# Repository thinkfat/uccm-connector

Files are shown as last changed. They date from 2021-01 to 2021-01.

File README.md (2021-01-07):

uccm-connector
==============

Connector board for UCCM GPSDO modules

This repository contains a KiCAD 5 project with a connector board for UCCM GPSDO boards.

Schematic
---------

The *doc* folder contains the schematic as PDF

Fabrication
-----------

The *gerber* folder contains Gerber plots and drill files. You can just ZIP this folder and upload it e.g. to JLCPCB to have the boards made.

BOM
---

Many of the passive parts are just generic beach sand stuff. If you look into the *bom* folder, there's a 
file _ibom.html_ that, if you open it in a browser, will give you an interactive part list that can guide you
with part ordering and assembly.

However, there's a few components that must match the footprint or are otherwise hard to find:

- DC jack: Lumberg NEB21R
- FPC socket: Molex 54132-5033
- FPC jumper cable: Molex 15166-0537
- Switching regulator: TI LMR14030SDDAR
- Storage coil: Coilcraft XAL5030-222MEC
- Flyback diode: Diodes B330BE-13
- Electrolytic caps: Panasonic EEE-FT1V470AR should fit
- Switcher input caps: TDK C3216X5R1H685K160AB
- Trimpot: Bourns 3313J-1-503E
- RS232 line converter: TI MAX3232ECDR
- DC input choke: Murata LQM31PN1R0M00L
- Reverse polarity protection: Diodes ES2BA-13-F
- LDO: APE8865N-33-HF-3

  this part is not really critical, just make sure you order a matching pin-out and take care of the dimensioning of the input and output caps.
  In fact even for this particular part you can deviate from the BOM and use 1µF MLCCs in 0805 size, they tend to be cheaper than the 4.7µF that
  are in the schematic.

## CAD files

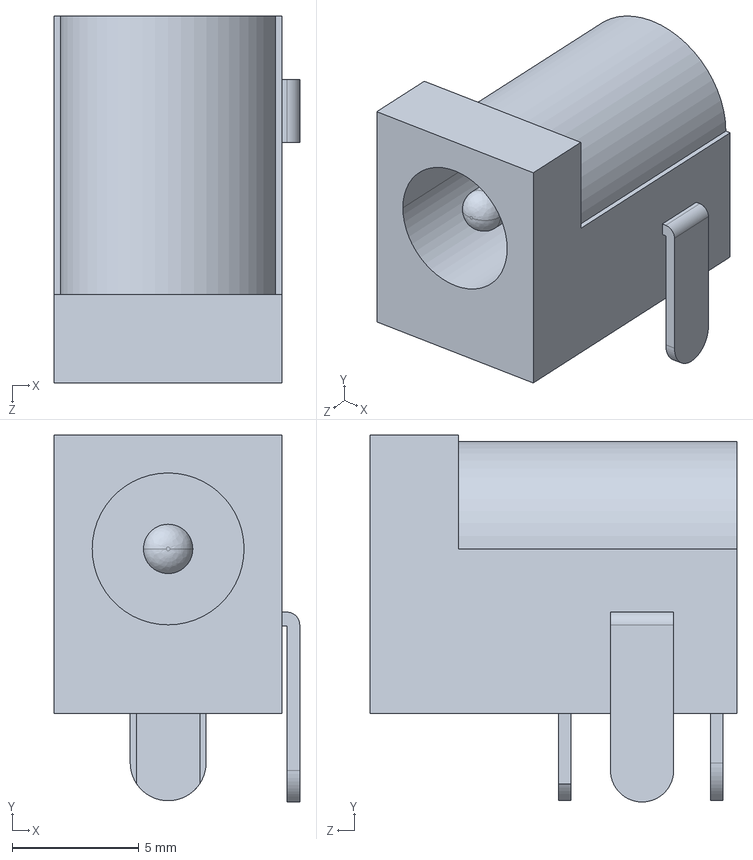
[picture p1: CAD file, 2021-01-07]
User Library-NEB21R.step
9.70 x 14.5 x 14.5 mm

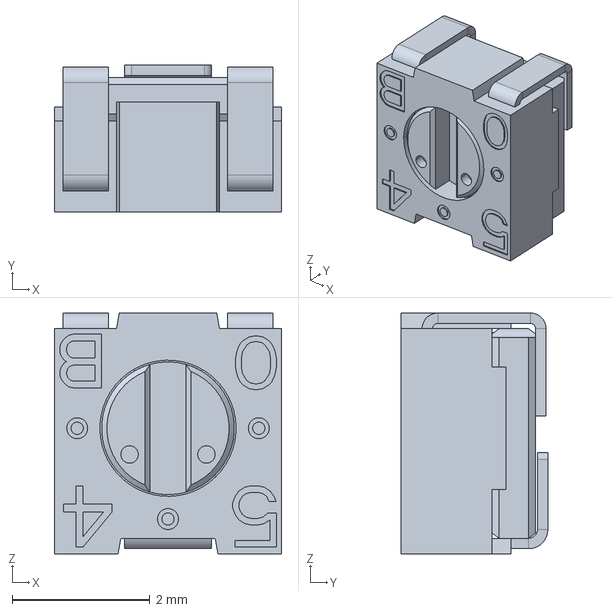
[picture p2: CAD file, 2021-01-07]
3313j-1-101e.stp
3.30 x 2.13 x 3.51 mm

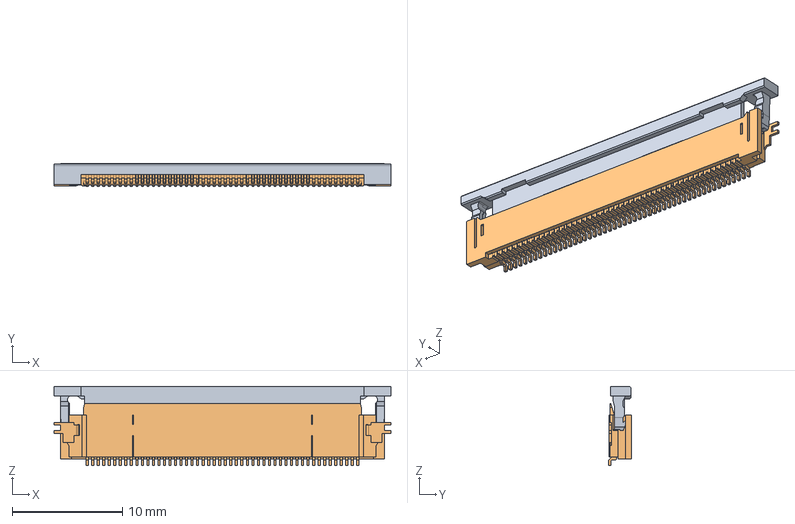
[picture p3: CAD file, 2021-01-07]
54132-5097.stp
30.5 x 2.05 x 7.15 mm

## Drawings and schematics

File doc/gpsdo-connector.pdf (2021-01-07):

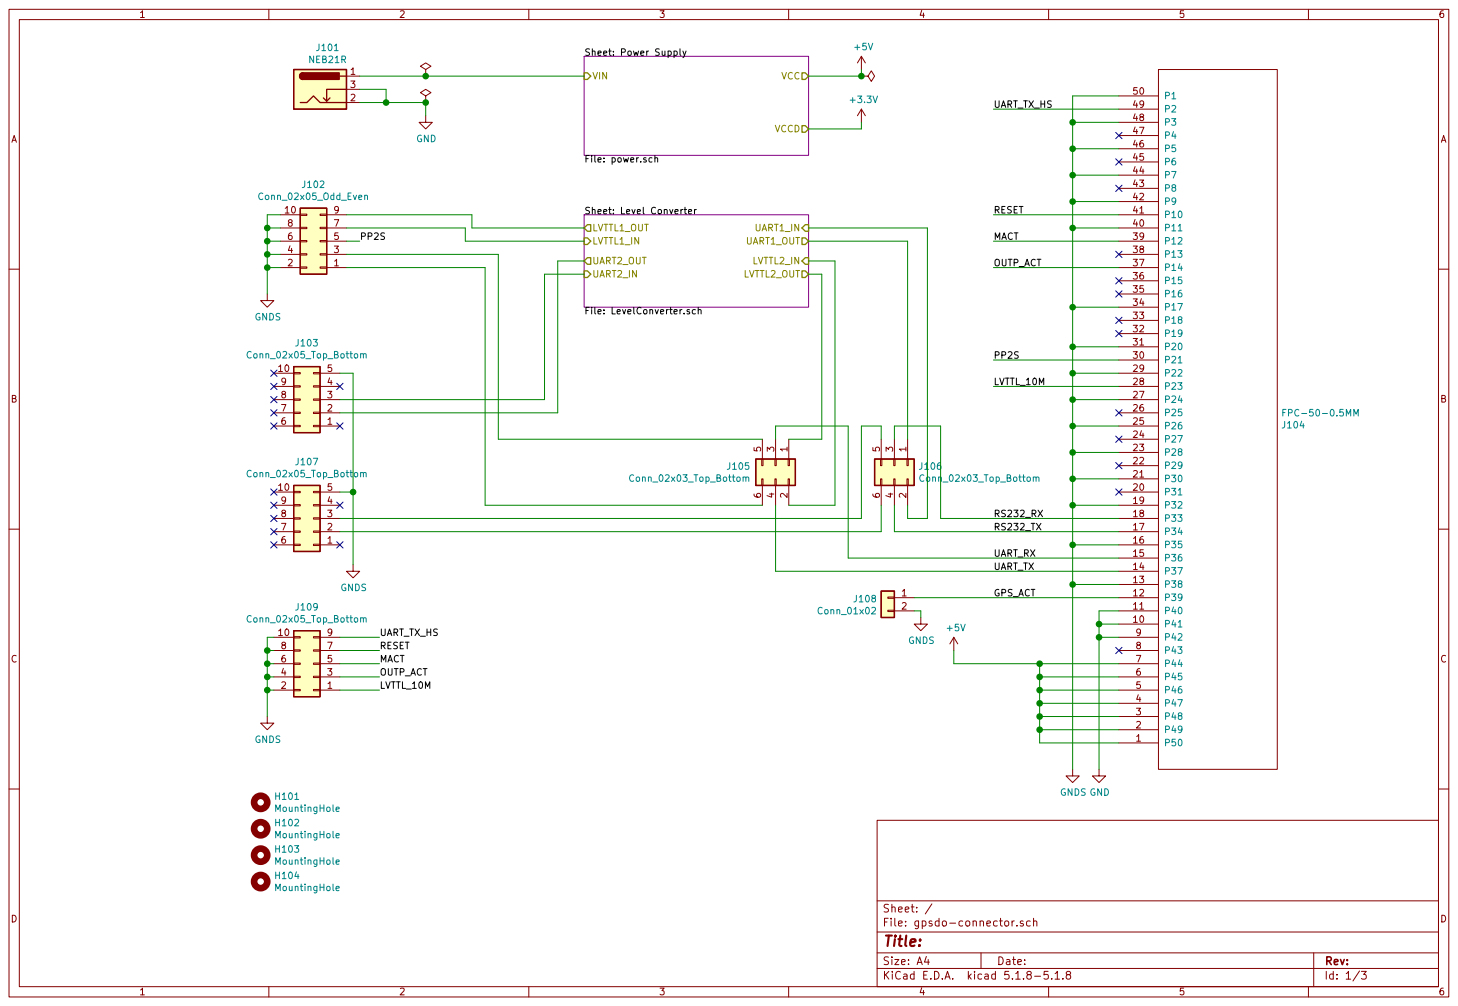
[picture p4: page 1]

Sheet: Level Converter File: LevelConverter.sch
LVTTL1_IN

File: gpsdo-connector.sch Sheet: /

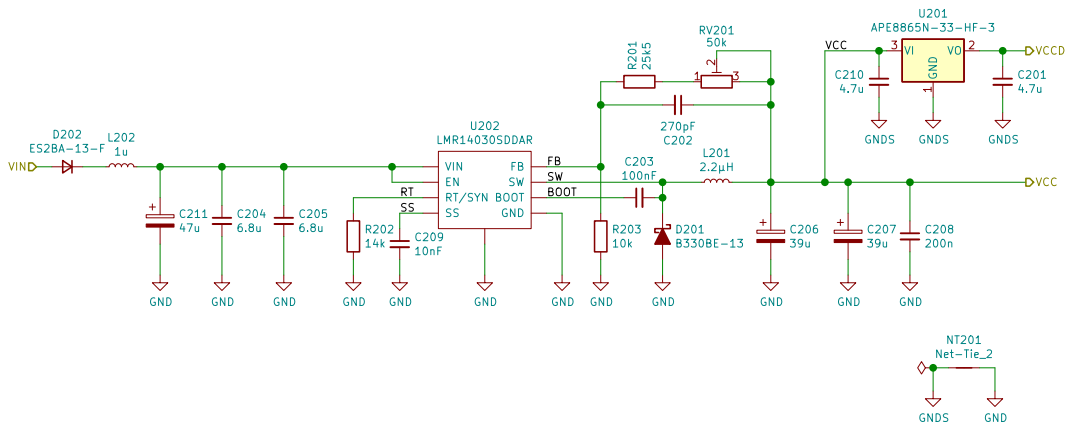
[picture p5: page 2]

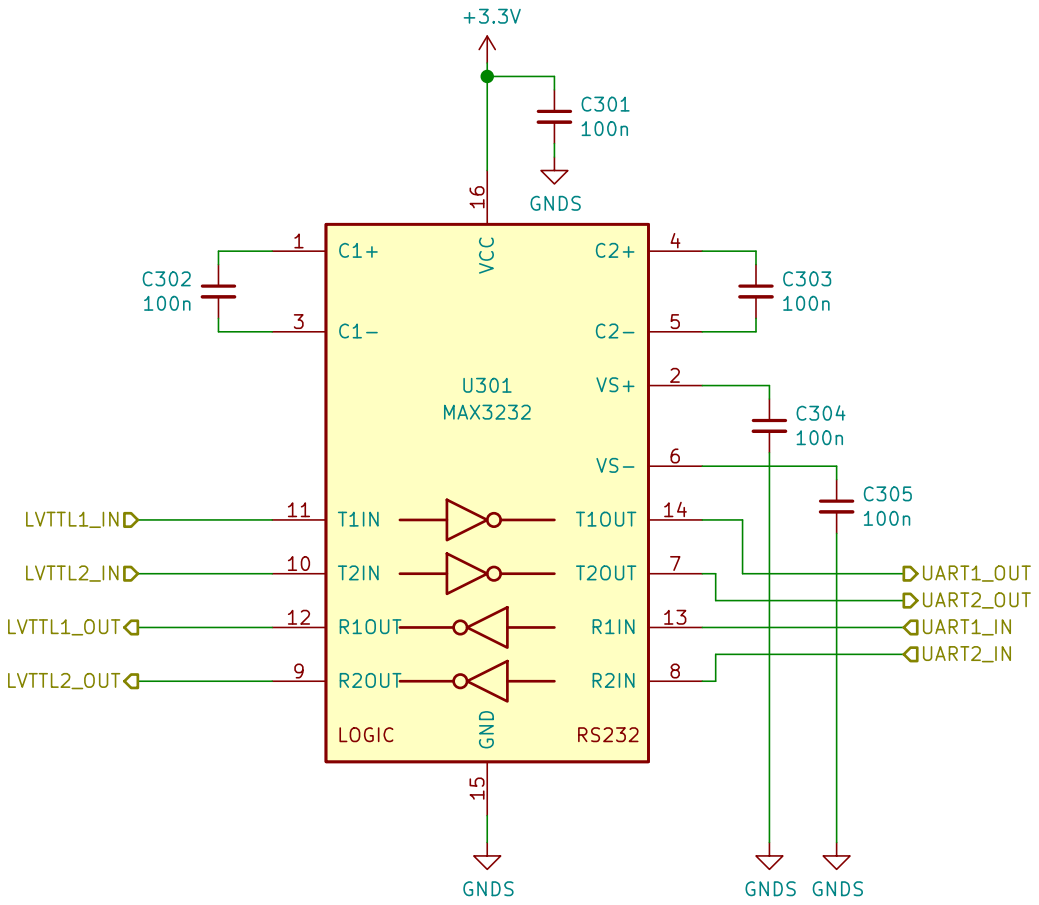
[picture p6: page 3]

Id: 3/3 Title: File: LevelConverter.sch Sheet: /Level Converter/

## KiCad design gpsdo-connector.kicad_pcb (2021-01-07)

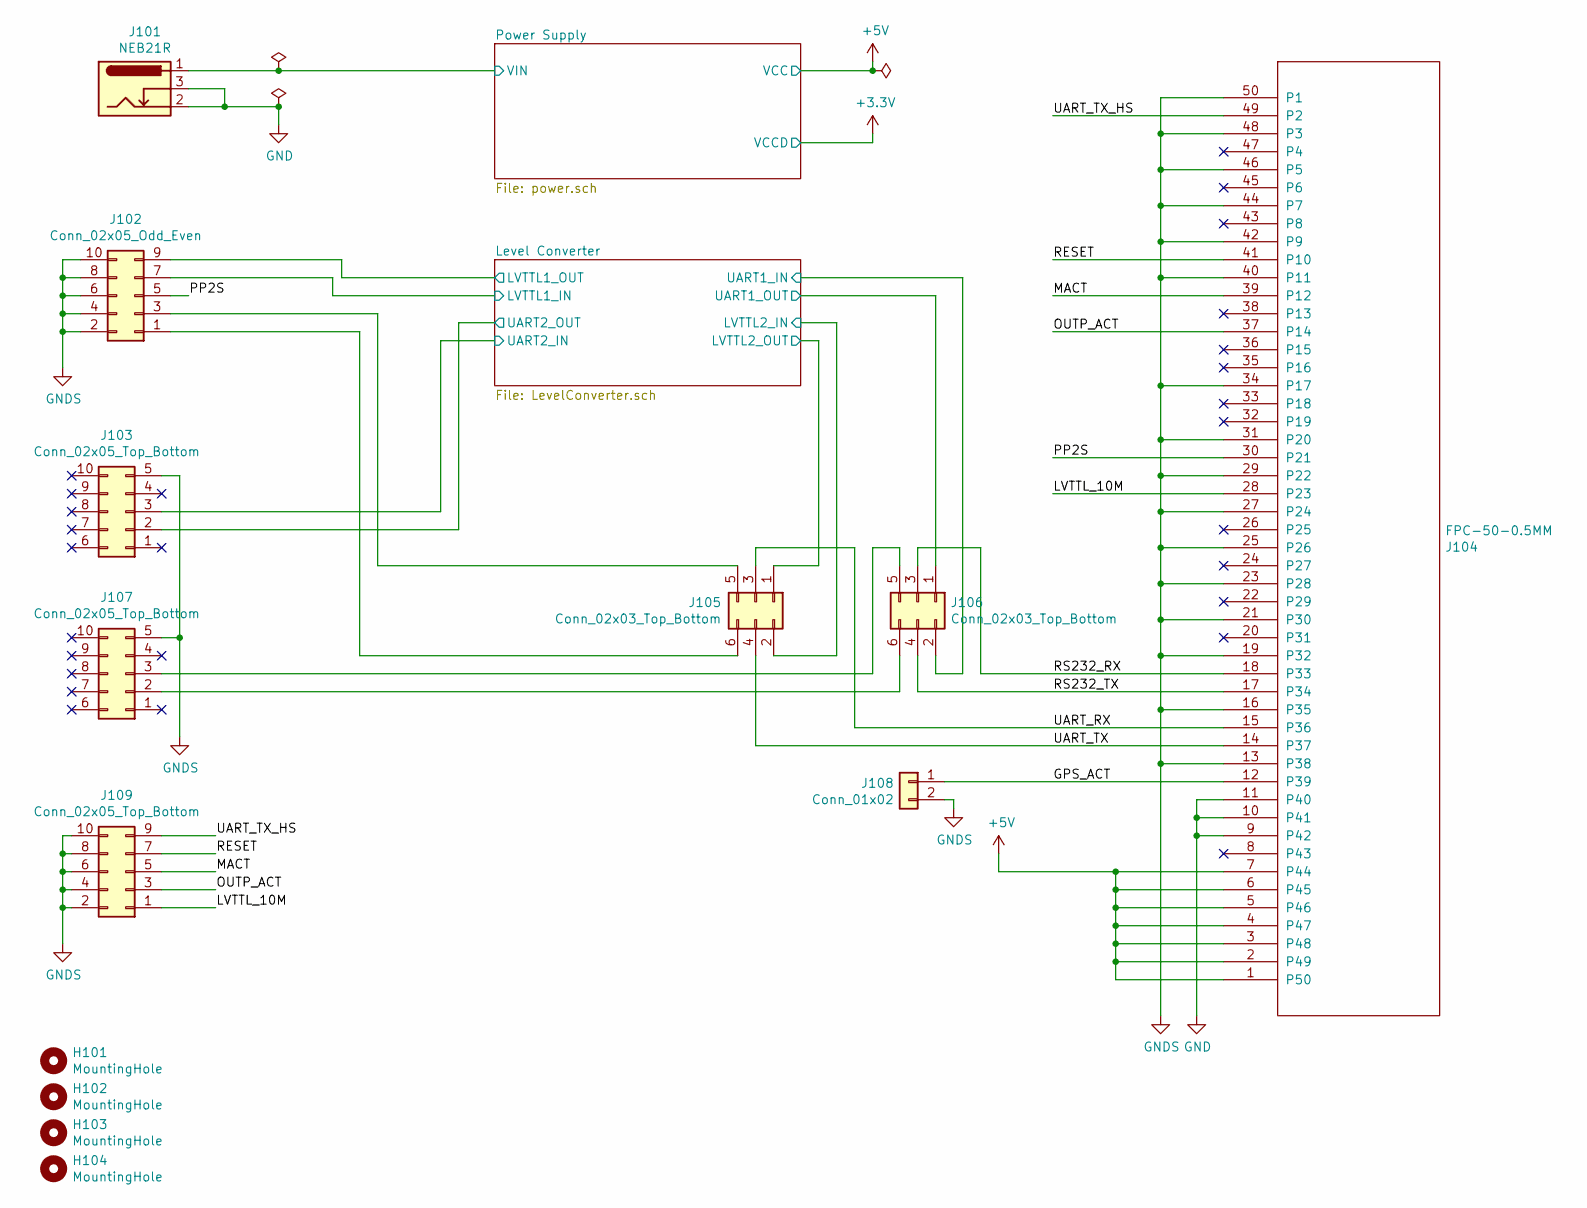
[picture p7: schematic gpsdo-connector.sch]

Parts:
H101, H102, H103, H104: MountingHole; MountingHole_3.2mm_M3_DIN965
J101: NEB21R
J102: Conn_02x05_Odd_Even; IDC-Header_2x05_P2.54mm_Vertical
J103, J107: Conn_02x05_Top_Bottom; IDC-Header_2x05_P2.54mm_Vertical
J104: FPC-50-0.5MM; Molex_54132-5033_1x50-1MP_P0.5mm_Horizontal
J105, J106: Conn_02x03_Top_Bottom; PinHeader_2x03_P2.54mm_Vertical
J108: Conn_01x02; PinHeader_1x02_P2.54mm_Vertical
J109: Conn_02x05_Top_Bottom; PinHeader_2x05_P2.54mm_Vertical

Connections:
+5V: J104.1 (P50), J104.2 (P49), J104.3 (P48), J104.4 (P47), J104.5 (P46), J104.6 (P45), J104.7 (P44); also elsewhere on the board
/GPS_ACT: J104.12 (P39), J108.1
/LVTTL_10M: J104.28 (P23), J109.1
/Level Converter/LVTTL1_IN: J102.7; also elsewhere on the board
/Level Converter/LVTTL1_OUT: J102.9; also elsewhere on the board
/Level Converter/LVTTL2_IN: J105.2; also elsewhere on the board
/Level Converter/LVTTL2_OUT: J105.1; also elsewhere on the board
/Level Converter/UART1_IN: J106.2; also elsewhere on the board
/Level Converter/UART1_OUT: J106.1; also elsewhere on the board
/Level Converter/UART2_IN: J103.3; also elsewhere on the board
/Level Converter/UART2_OUT: J103.2; also elsewhere on the board
/MACT: J104.39 (P12), J109.5
/OUTP_ACT: J104.37 (P14), J109.3
/PP2S: J102.5, J104.30 (P21)
/Power Supply/VIN: J101.1; also elsewhere on the board
/RESET: J104.41 (P10), J109.7
/RS232_RX: J104.18 (P33), J106.3
/RS232_TX: J104.17 (P34), J106.4
/UART_RX: J104.15 (P36), J105.3
/UART_TX: J104.14 (P37), J105.4
/UART_TX_HS: J104.49 (P2), J109.9
GND: J101.2, J101.3, J104.9 (P42), J104.10 (P41), J104.11 (P40); also elsewhere on the board
GNDS: J102.2, J102.4, J102.6, J102.8, J102.10, J103.5, J104.13 (P38), J104.16 (P35), J104.19 (P32), J104.21 (P30), J104.23 (P28), J104.25 (P26), J104.27 (P24), J104.29 (P22), J104.31 (P20), J104.34 (P17), J104.40 (P11), J104.42 (P9), J104.44 (P7), J104.46 (P5), J104.48 (P3), J104.50 (P1), J107.5, J108.2, J109.2, J109.4, J109.6, J109.8, J109.10; also elsewhere on the board
unnamed: J102.1, J105.6
unnamed: J102.3, J105.5
unnamed: J106.5, J107.3
unnamed: J106.6, J107.2

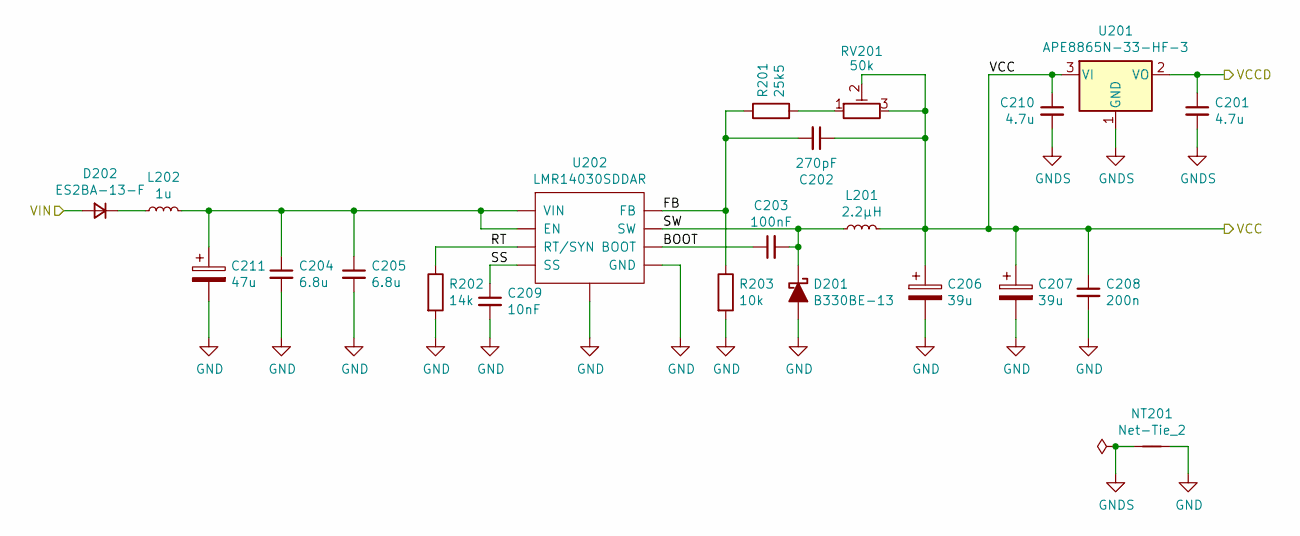
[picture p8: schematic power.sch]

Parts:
C201, C210: 4.7u; C_0805_2012Metric
C202: 270pF; C_0805_2012Metric
C203: 100nF; C_0805_2012Metric
C204, C205: 6.8u; C_1206_3216Metric
C206, C207: 39u; CP_Elec_5x5.9
C208: 200n; C_0805_2012Metric
C209: 10nF; C_0805_2012Metric
C211: 47u; CP_Elec_5x5.9
D201: B330BE-13; D_SMB
D202: ES2BA-13-F; D_SMA
L201: 2.2µH; L_Coilcraft_XAL5030
L202: 1u; L_1206_3216Metric
NT201: Net-Tie_2; NetTie-2_SMD_Pad2.0mm
R201: 25k5; R_0805_2012Metric
R202: 14k; R_0805_2012Metric_Pad1.15x1.40mm_HandSolder
R203: 10k; R_0805_2012Metric_Pad1.15x1.40mm_HandSolder
RV201: 50k; Trimpot_Bourns_3313J-1
U201: APE8865N-33-HF-3; SOT-23
U202: LMR14030SDDAR; TI_SO-PowerPAD-8

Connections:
+3V3: C201.1, U201.2 (VO); also elsewhere on the board
+5V: C202.1, C206.1, C207.1, C208.1, C210.1, L201.2, RV201.2, RV201.3, U201.3 (VI); also elsewhere on the board
/Power Supply/BOOT: C203.1, U202.1 (BOOT)
/Power Supply/FB: C202.2, R201.1, R203.1, U202.5 (FB)
/Power Supply/RT: R202.1, U202.4 (RT/SYN)
/Power Supply/SS: C209.1, U202.6 (SS)
/Power Supply/SW: C203.2, D201.1 (K), L201.1, U202.8 (SW)
/Power Supply/VIN: D202.2 (A); also elsewhere on the board
GND: C204.2, C205.2, C206.2, C207.2, C208.2, C209.2, C211.2, D201.2 (A), NT201.2, R202.2, R203.2, U202.7 (GND), U202.9; also elsewhere on the board
GNDS: C201.2, C210.2, NT201.1, U201.1 (GND); also elsewhere on the board
unnamed: C204.1, C205.1, C211.1, L202.2, U202.2 (VIN), U202.3 (EN)
unnamed: D202.1 (K), L202.1
unnamed: R201.2, RV201.1

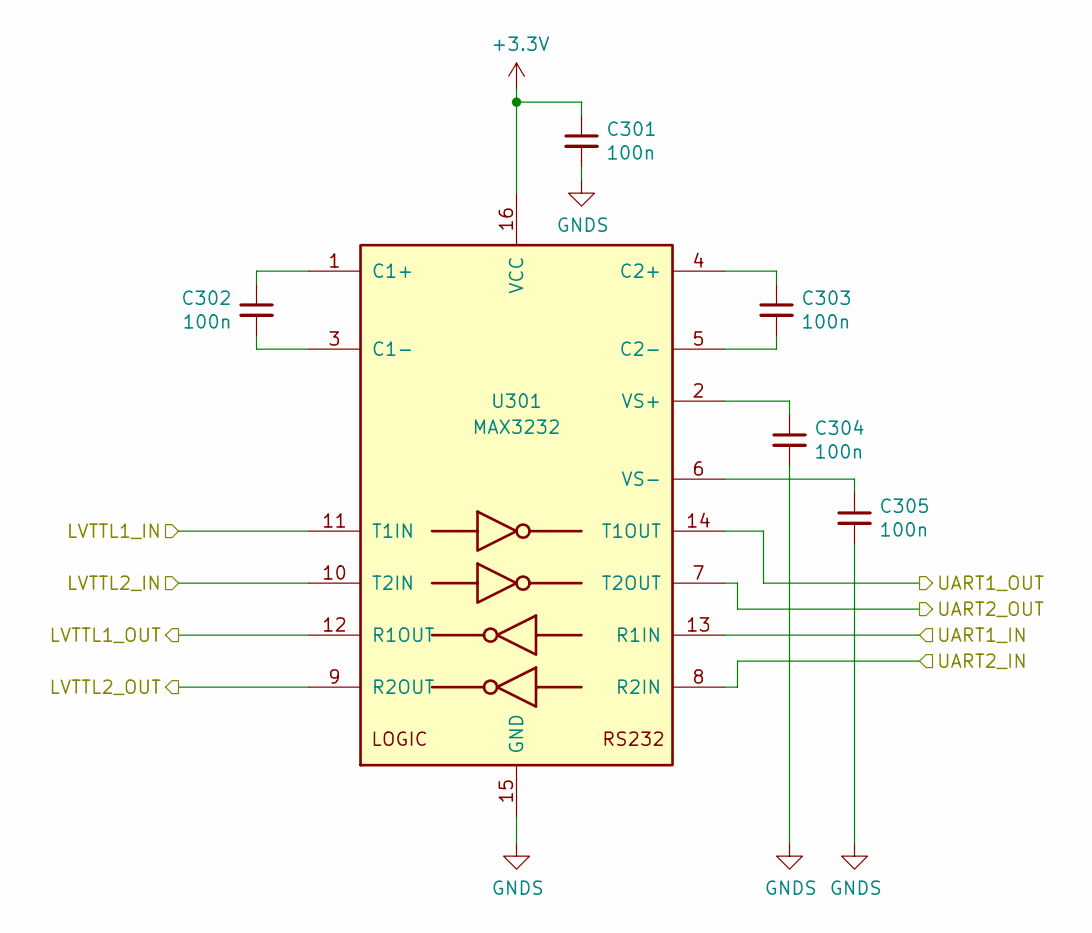
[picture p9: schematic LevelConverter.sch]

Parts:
C301, C302, C303, C304, C305: 100n; C_0805_2012Metric
U301: MAX3232; SOIC-16_3.9x9.9mm_P1.27mm

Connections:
+3V3: C301.1, U301.16 (VCC); also elsewhere on the board
/Level Converter/LVTTL1_IN: U301.11 (T1IN); also elsewhere on the board
/Level Converter/LVTTL1_OUT: U301.12 (R1OUT); also elsewhere on the board
/Level Converter/LVTTL2_IN: U301.10 (T2IN); also elsewhere on the board
/Level Converter/LVTTL2_OUT: U301.9 (R2OUT); also elsewhere on the board
/Level Converter/UART1_IN: U301.13 (R1IN); also elsewhere on the board
/Level Converter/UART1_OUT: U301.14 (T1OUT); also elsewhere on the board
/Level Converter/UART2_IN: U301.8 (R2IN); also elsewhere on the board
/Level Converter/UART2_OUT: U301.7 (T2OUT); also elsewhere on the board
GNDS: C301.2, C304.2, C305.2, U301.15 (GND); also elsewhere on the board
unnamed: C302.1, U301.1 (C1+)
unnamed: C302.2, U301.3 (C1-)
unnamed: C303.1, U301.4 (C2+)
unnamed: C303.2, U301.5 (C2-)
unnamed: C304.1, U301.2 (VS+)
unnamed: C305.1, U301.6 (VS-)

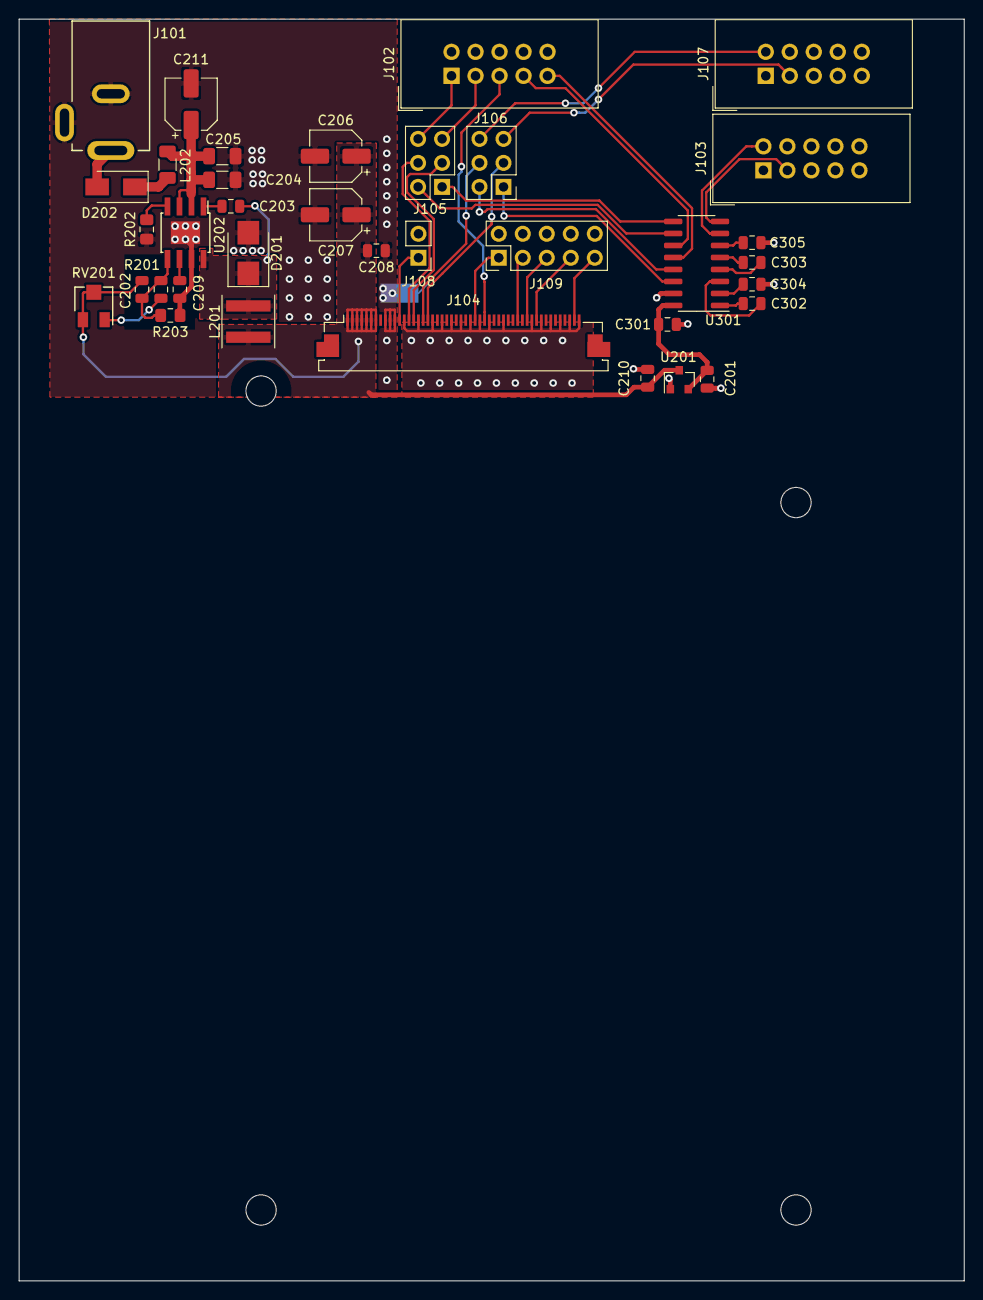
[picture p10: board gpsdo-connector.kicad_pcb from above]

Board: 2 copper layers, 100.0 x 133.5 mm, 41 parts (1 on the bottom side), 42 nets.
